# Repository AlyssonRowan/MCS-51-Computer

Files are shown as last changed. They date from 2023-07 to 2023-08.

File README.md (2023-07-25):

# MCS-51-Modular-Computer

MCS-51 based highly modular computer system
-------------------------------------------

This project aims to bring forward an MCS-51 based 
computer system centered around a series of relatively
simple modules sharing a modular bus backplane.

The overall design uses a number of boards designed within 
the limitations of low-cost PCB prototyping houses and free
PCB design software, i.e.
- Two signal planes (front and back)
- A maximum board size of 100mm x 100mm
  (yes, I know that some of them limit you to 100 x 80mm)
- A maximum of 300 connections per PCB
- A maximum of 2 signal (or groundplane) layers

Three card sizes have been defined and templates generated
based on the 1U Eurocard - 
- Full 1U Eurocard (100mm x 160mm)
- Half 1U Eurocard (100mm x 80mm)
- Short 1U Eurocard (100mm x 100mm)

These templates include placement masks for the bus connectors

NOTE:
----
Some of the simpler boards exist only as PCB files,
in these cases, component values are marked on-board
instead of component references.

The affected boards are:
- Modular Backplane (2 boards)
- 4-slot Production Backplane
- Integrated Backplane (MOBO and daughterboard)
- Bus Daisy-Chain board

Central Processor Board
-----------------------
- HMC-PR-1 AT89s51 Processor Board

The processor chosen for this project is the Atmel
AT89S51 and AT89S52 microcontroller. These have
4k and 8k of ISP Flash Memory respectively.

The processor board is set up without user SRAM and 
is ready to accept firmware as a basic development 
board. The serial lines are buffered and brought out 
to a header (TTL signals) for connection to a user 
console. RS232 is available via the Front Panel board.

Console (serial) signals are also carried on the bus
ready for embedded terminal hardware.

Main Memory Boards
------------------
- HMC-MMB-1   HY6264A (8k x 8bit SRAM) x 4
- HMC-MMB-2 - Configurable W24257AJ (32k x 8bit SRAM)

Two versions have so far been designed 
- one accepts a 32k x 8 fast SRAM chip, and is 
configurable in 8kB blocks.
- the second accepts up to 4 8k x 8 fast SRAM chips

Both versions may be located in upper OR lower memory space.
Up to two of these boards may be installed.

Program ROM Boards (Under development)
------------------
Ultimately, these boards will accept

- UV-EPROM
- EEPROM
- FLASH PROM

And will provide storage for compiled programs
(upper PStore) and System programs (lower PStore)

Modular Computer Bus
--------------------
The decision was made to use low-cost, highly available
standard 0.1" double row headers in order to reduce the 
board pin count while providing just a few spare lines 
above the bus minimum requirement. These are the same 
connectors formerly used for PC floppy and hard disk 
drives.

Although polarity is respected, just in case ribbon cable
is used, it is actually maintained by the polarisation 
forced by the dissimilar connectors on the backplane.

Modular Backplane
-----------------
- HMC-MB-1 (Slot A)
- HMC-MB-2 (Slot B)

The backplane comprises two boards, one carrying the 
40-way bus that includes the default signals from the 
MCS-51 MPU and the other, a 24-way bus with additional 
signals and 5V power. This second board also includes
decoupling capacitors per backplane slot.

The two boards are designed to sit side by side, and are
able to be stacked, extending the basic backplane from 
the basic five slots to (theoretically) any number of 
slots. It is not recommended that more than two modules
be daisy-chained without bus terminations.

A separate, hard wired 5.0V 2A (or more) power supply is
required to power the bus.

M2 mounting holes are provided for attachment of lateral 
support bars (Grounded, recommend: 6mm square Aluminium,
use M2 stainless washers to stand off from PCB) and cage 
sides (Isolated, recommend: 4mm acrylic). Half-holes are 
provided on the junction between the two boards in order
to facilitate a third point of attachment to the support 
bars.

Integrated Backplane
--------------------
- HMC-IB-1 (MOBO)
- HMC-IB-2 (Bus)

This is a pair of boards that are stacked using extended 
pin header sockets. 

The motherboard is a single 100mm square board which
includes basic front panel functionality and power feed
to the bus. A separate, hard wired power supply (5.0V 2A) 
is required.

The daughterboard provides a 4-slot bus powered via the 
motherboard.

It is recommended that this item not be daisy-chained
without very careful consideration. The board is fused
at 2A.

There is no RS232 console option on this PCB. This needs
to be provided separately if required. 

A low frequency clock "pulse" generator is provided for 
applications that require a low-frequency, semi-stable 
clock pulse for operation in the development stage.

The daughter board, built with standard sockets (i.e.
not wire-wrap form) may be used independent of the parent
board as a simple, no-frills 4-slot backplane. A mountable
version of this PCB is available.

With only a plug and a socket, the daughter board could 
also be used as a slot extender for service use.

4-Slot Production Backplane
---------------------------
- HMC-PB-1

This is functionally identical to the 4-slot daughterboard
for the integrated backplane kit, though with the addition
of mounting holes.

Daisy Chain Boards
------------------
- HMC-DCB-1 Short link for Modular Backplane use
- HMC-DCB-2 Long link for integrated backplane use

These board are supplied as two separate PCBs.

One narrow PCB for interlinking two Modular Backplane
segments while maintaining system board separation.
The wider is for linking an integrated backplane with 
a modular backplane segment.

Linking an integrated backplane with a modular backplane
is not recommended other than for development purposes.

Active Bus Terminator
---------------------
- HMC-ABT-1
While not strictly necessary, this short board is designed
to be inserted in the first and last physical slots on the 
bus, and should reduce signal reflections and timing issues
on the bus - especially when a longer bus is used.

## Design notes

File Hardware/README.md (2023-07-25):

HARDWARE
--------

Assemblies are divided into the following categories:

- (a) Templates
- (b) Core Components
- (c) Enhanced Options
- (d) Advanced Options
- (e) Fun and Aesthetic Options
- (f) Sensors and Ancillary Options
- (g) Support Hardware

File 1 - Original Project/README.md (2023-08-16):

# Original Project
**Elektor BASIC Computer**
*Elektor December 1987*

For a while, the MCS-51 range of microcontrollers 
was probably the most accessible on the market. 
The introduction of the 8052AH-BASIC gave a number
of hobbyists their first taste of microcontrollers, 
with the capacity to create a single-board computer
that was both a control system and a development 
system using a high-level language as opposed to
having to face the challenge of programming in 
assembler.

The project articles are included in their entirity.

Sadly the 8052AH-BASIC is no longer available.

I still use the board I built at that time even 
though it is now more than 30 years old.

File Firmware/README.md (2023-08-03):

# MCS-51 Modular Computer - Firmware

BASIC-52
--------

BASIC-52 was originally developed by Intel for their
8052AH-BASIC chip - an 8052 microcontroller with an 
on-board BASIC interpreter.

Please consider this to be a codebase from which to
develop your own MCS-51 support firmware.

V1.0 was the original release on these devices, but 
was rapidly supplanted by V1.1 which included a number 
of enhancements and bugfixes.

V1.1 continued to be supplied throughout the life of the
device, even though there were bugs in parts of the code.

V1.1++ was a patch for the V1.1 ROM image correcting the
most severe of these bugs.

V1.2 was independently developed to enable 8032 and 8052
devices to run using an off-chip ROM.

V1.3 is designed for devices to run code that allows for
the programming of FLASH PROMs

WARRANTY
--------

None of this software carries any warranty whatsoever and
MAY NOT be used for mission-critical applications including
but not limited to avionic systems, vehicle system control,
medical or safety systems.

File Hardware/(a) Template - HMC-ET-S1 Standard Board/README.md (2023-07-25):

HMC-ET-S1 Standard Board
------------------------

This schematic template may be used with any of the 
standard board PCB templates.

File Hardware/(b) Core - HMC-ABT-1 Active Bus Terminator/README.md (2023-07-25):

Active Bus Terminator
---------------------
- HMC-ABT-1

NOTE: 2 terminators are required if used.

While not strictly necessary, this short board is designed
to be inserted in the first and last physical slots on the 
bus, and should reduce signal reflections and timing issues
on the bus - especially when a longer bus is used.

It may be necessary to adjust the target voltage of one or
both terminator channels in order to reduce standing current 
on the bus.

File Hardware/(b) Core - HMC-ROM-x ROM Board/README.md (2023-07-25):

HMC-ROM-1 - 2764/27128 ROM Board v1.00
--------------------------------------

This is an interface designed to allow a pre-written EPROM
to be read by the processor. Both 2764 and 27127 EPROMs
may be used. The device only appears in the /PS address space

While the board may be configured by 8k blocks, while using
27128 EPROMs, the lower address should always be on a 16k 
boundary.

PROMs placed at the lower limit of the upper 32k of memory
(i.e. starting at 8000H) will allow the MCS-51 BASIC-52 
interpreter to access stored programs directly.

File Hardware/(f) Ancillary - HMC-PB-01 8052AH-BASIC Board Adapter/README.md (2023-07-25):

HMC-PB-01 8052AH-BASIC Board Adapter
------------------------------------

This PCB is designed to consolidate the signals on
the original Elektor 8052AH-BASIC Basic Computer
project board for compatibility with the MCS-51
Modular Computer.

Note that without modification, the console port
is NOT brought out to the bus and that a second
serial port output is available, exposed at the
port on this board.

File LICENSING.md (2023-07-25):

The content of this repository is released under the terms
of the GNU GENERAL PUBLIC LICENSE Version 3

Hardware
--------
While the ownership of the intellectual property of the
hardware is entirely in the hands of the owner of this 
repository, it carries some limitations from the software 
used to design it.

The version of DipTrace used is limited to non-commercial
applications only, so any derivative works would need to 
be re-developed using a less restrictive application.

The design paradigm, however, is based on the use of 100mm
wide PCBs and a shared bus design. You are asked to respect 
both of these factors in your own application in order to
maintain functional and physical compatibility.

Software & Firmware
-------------------
The firmware for this project is fixed firmly as a derivative 
work and will be subject to the copyrights of its various
owners. 

Attribution and Derivative Works
--------------------------------
You are asked to leave all copyright and attribution notices
in the source files of your derivative works.

EGO: You are asked to contact the owner of this repository 
should you find it useful.

Limitations and Liability
-------------------------
This hardware and software property is shared without cost. 
No representation as to merchantability or fitness for purpose
is made whatsoever. Liability for damage consequential to
using any part of this project lies entirely in the hands of 
the user.

Specific exclusions:
No part of this project is to be used for any medical, clinical,
avionic or other system where software or hardware failure could
lead to losses, injury or death. Those systems are designed by
specialist experts for a very good reason.

A.Rowan, 09 July 2023

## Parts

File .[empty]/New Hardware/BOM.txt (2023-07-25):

HMC-XXX-X BoardName

Line	Ref Des		        			Name			Value		QTY
---------------------------------------------------------------------------------------------------

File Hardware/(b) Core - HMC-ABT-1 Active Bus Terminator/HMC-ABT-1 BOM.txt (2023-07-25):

HMC-ABT-1  Active Bus Terminator v1.00

Line	Ref Des		        			Name			Value		QTY
---------------------------------------------------------------------------------------------------
1	C1, C2, C3					Capacitor Polarised	100uF 6.3V	3
2	C4, C5,						Capacitor Polarised	47uF 6.3V	2
3	C6, C7, C8, C9, C10, C11, C12, C13, C14		Capacitor		0.1uF		9
4	J1A						34-pin angle header, Male, 2.54mm	1
5	J1B						40-pin angle header, Male, 2.54mm	1
6	Q1, Q2						2N4923G					2
7	R3, R4,						Resistor		56R 1/4W	2
8	R5, R6, R7, R8, R9, R10, R11, R12, R13		SIP 9 Res (commoned)	1k0		9
9	TP1, TP2, TP3, TP4, TP5,			TESTPOINT				5
10	U1						LM358N					1
11	VR1, VR2					201XR103B		100k		2

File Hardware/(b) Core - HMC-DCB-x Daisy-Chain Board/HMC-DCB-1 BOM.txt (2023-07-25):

HMC-DCB-1  Daisy-Chain Board (short) v2.00

Line	Ref Des		        			Name			Value		QTY
---------------------------------------------------------------------------------------------------
1	J1A, J2A					40 pin straight header, FEMALE, 2.54mm	2
2	J1B, J2B					34 pin straight header, FEMALE, 2.54mm	2

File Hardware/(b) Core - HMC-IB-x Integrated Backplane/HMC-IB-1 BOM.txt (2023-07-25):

HMC-IB-1  Integrated Backplane MOBO v1.65

Line	Ref Des		        			Name			Value		QTY
---------------------------------------------------------------------------------------------------
1       C1, C2                                          Capacitor, polarised    250uF 6.3V      2
2       C3, C4, C5, C7, C10                             Capacitor, polarised    100uF 6.3V      5
3       C6                                              Capacitor               0.1uF           1
4       C9                                              Capacitor               10nF            1
5       D1                                              LED-5R_Red              5mm Round       1
6       D2, D3, D4, D5, D6, D7, D8, D9                  LED-3R_Red              3mm Round       8
7       J2, J3, J5, J7, J8, J11, J12, J13, J14          2 pin straight header, FEMALE, 2.54mm   9
8       J4, J6, J9, J10                                 6 pin straight header, FEMALE, 2.54mm   4
9       P1                                              14 pin straight header, MALE, 2.54mm    1
10      R1, R2, R4, R5, R6, R7, R8, R9                  RESISTOR                360R 0.125W     8
11      R3, R11                                         RESISTOR                3k9 0.125W      2
12      R10                                             Potentiometer, Preset   100k            1
13      S1, S2                                          7101SD9CQE              SPDT 5A 120V    2
14      S3                                              7201P3YCQE              DPDT 5A 120V    1
15      TP1, TP2, TP3                                   TESTPOINT                               3
16      U1                                              ULN2003BDR                              1
17      U2                                              NE555D                                  1

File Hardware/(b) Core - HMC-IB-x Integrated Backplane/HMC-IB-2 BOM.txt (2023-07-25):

HMC-IB-2  Integrated Backplane BUS daughterboard v1.10

Line	Ref Des		        			Name			Value		QTY
---------------------------------------------------------------------------------------------------
1	J1A						40-pin angle header, FEMALE		4
2	J1B						34-pin angle header, FEMALE, wire-wrap	4

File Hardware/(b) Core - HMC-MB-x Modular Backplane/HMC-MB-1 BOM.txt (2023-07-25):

HMC-MB-1  Modular Backplane A 

Line	Ref Des		        			Name			Value		QTY
---------------------------------------------------------------------------------------------------
5	J1A, J2A, J3A, J4A, J5A, J6A, J7A		40-pin straight header, FEMALE		7

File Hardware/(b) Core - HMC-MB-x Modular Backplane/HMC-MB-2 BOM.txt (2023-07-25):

HMC-MB-2  Modular Backplane A 

Line	Ref Des		        			Name			Value		QTY
---------------------------------------------------------------------------------------------------
1	J1B, J2B, J3B, J4B, J5B, J6B, J7B		34-pin straight header, FEMALE		7
2	C2, C3, C4, C5, C6				CAPACITOR, polarised	100uF 6.3V	5

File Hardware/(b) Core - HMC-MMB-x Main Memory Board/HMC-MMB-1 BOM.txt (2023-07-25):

HMC-MMB-1 - Main Memory Board (HY6264A x 4) v1.00 

Line	Ref Des		        			Name			Value		QTY
---------------------------------------------------------------------------------------------------
1	C1						Capacitor Polarised 	1000uF 16V	1
2 	C2, C3, C4, C5 					Capacitor		0.1uF		4
3 	D1 						1N5817G					1
4 	J1						40-pin angle header, Male, 2.54mm	1
5	J2						34-pin angle header, Male, 2.54mm	1
6	J3 						6-pin angle header, Male, 2.54mm	1
7 	JP1, JP2, JP3, JP4				Jumper Point 3-in-line, 2.54mm		4
8	U1, U2, U3, U4					HY6264A					4
9	U1, U2, U3, U4					Socket, 22pin 				4

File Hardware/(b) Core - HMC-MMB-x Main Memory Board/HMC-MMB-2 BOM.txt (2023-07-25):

HMC-

Line	Ref Des		        			Name			Value		QTY
---------------------------------------------------------------------------------------------------
1 	C1, C4 						Capacitor		0.1uF 		2
2 	C2 						Capacitor Polarised	1000uF 16V	1
3	D1						1N5817G 				1
4	J1						40-pin angle header, Male, 2.54mm	1
5	J2						34-pin angle header, Male, 2.54mm	1
6	J3 						6-pin angle header, Male, 2.54mm	1
7	JMP1						Jumper Point 3-in-line, 2.54mm		1
8 	JMP2, JMP3, JMP4, JMP5				Jumper Point 3-square, 2.54mm		4
10	U4						W24257AJ				1

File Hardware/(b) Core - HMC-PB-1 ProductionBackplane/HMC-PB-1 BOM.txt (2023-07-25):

HMC-PB-1  ProductionBackplane (4 slot bus) v1.00

Line	Ref Des		        			Name			Value		QTY
---------------------------------------------------------------------------------------------------
1	C1						Capacitor Polarised	100uF 6.3V	1
4	J1A, J2A, J3A, J4A				40-pin straight header, FEMALE		1
5	J1B, J2B, J3B, J4B				34-pin straight header, FEMALE		1

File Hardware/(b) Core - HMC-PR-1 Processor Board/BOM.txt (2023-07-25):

HMC-PR-1  Processor Board v1.20

Line	Ref Des		        			Name			Value		QTY
---------------------------------------------------------------------------------------------------
1 	C1, C3, C4, C8 					Capacitor		0.1uF		4
2	C2						Capacitor Polarised	1000uF 16V	1
3	C5						Capacitor Polarised 	10uF 16V	1
4 	C6, C7						Capacitor		30pF		2
5	D1 						1N5817G					1
6	J1						40-pin angled header, MALE, 2.54mm	1
7 	J2						34-pin angled header, MALE, 2.54mm	1
8	J3						10-pin angled header, MALE, 2.54mm	1
9 	J4						8-pin angled header, MALE, 2.54mm	1
10	J5						6-pin angled header, MALE, 2.54mm	1
11	J6						14-pin angled header, MALE, 2.54mm	1
12	JP1						Jumper Point 3-in-line, 2.54mm		1
13	R1						Resistor		8k2 0.25W	1
14	R2						Resistor		SIL 10k *8	1
15 	SW1						SP (ON)-OFF				1
16	U1						74HCT154N				1
17	U2						AT89S52-24PU				1
18	U3						74HC34N					1
19	U4						74HCT573N				1
20	Y1						ECS-20-20-1		12MHz		1
21	Misc Hardware					Sockets for above ICs

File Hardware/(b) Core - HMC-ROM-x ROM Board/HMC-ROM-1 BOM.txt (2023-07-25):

HMC-ROM-1 2764, 128 ROM Board v1.00 

Line	Ref Des		        			Name			Value		QTY
---------------------------------------------------------------------------------------------------
1	C1						Capacitor Polarised	1000uF 16V	1
2	C2, C3						Capacitor		0.1uF		2
3	D1						1N5817G					1
4	J1						40-pin angle header, Male, 2.54mm	1
5	J2						34-pin angle header, Male, 2.54mm	1
6	J3						6-pin angle header, Male, 2.54mm	1
7	JMP1						Jumper 3-in-line, 2.54mm		3
8	JMP2, JMP3, JMP4, JMP5, JMP6, JMP7, JMP8, JMP9	Jumper 3-square, 2.54mm			8
9	R1, R2						Resistor		4k7 0.25W	2
10	U1						SN74HC21N				1
11	U3						27128A-2				1

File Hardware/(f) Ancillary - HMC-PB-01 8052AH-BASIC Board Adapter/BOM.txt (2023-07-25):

HMC-PB-01 8052AH-BASIC Board Adaptor v1.00

Line	Ref Des		        			Name			Value		QTY
---------------------------------------------------------------------------------------------------
1	D1						1N5817G					1
2	J1, J3						40-pin angle header, Male		2
3	J2						34-pin angle header, Male		1
4	J4						20-pin angle header, Male		1
5	J5						8-pin angle header, Male		1

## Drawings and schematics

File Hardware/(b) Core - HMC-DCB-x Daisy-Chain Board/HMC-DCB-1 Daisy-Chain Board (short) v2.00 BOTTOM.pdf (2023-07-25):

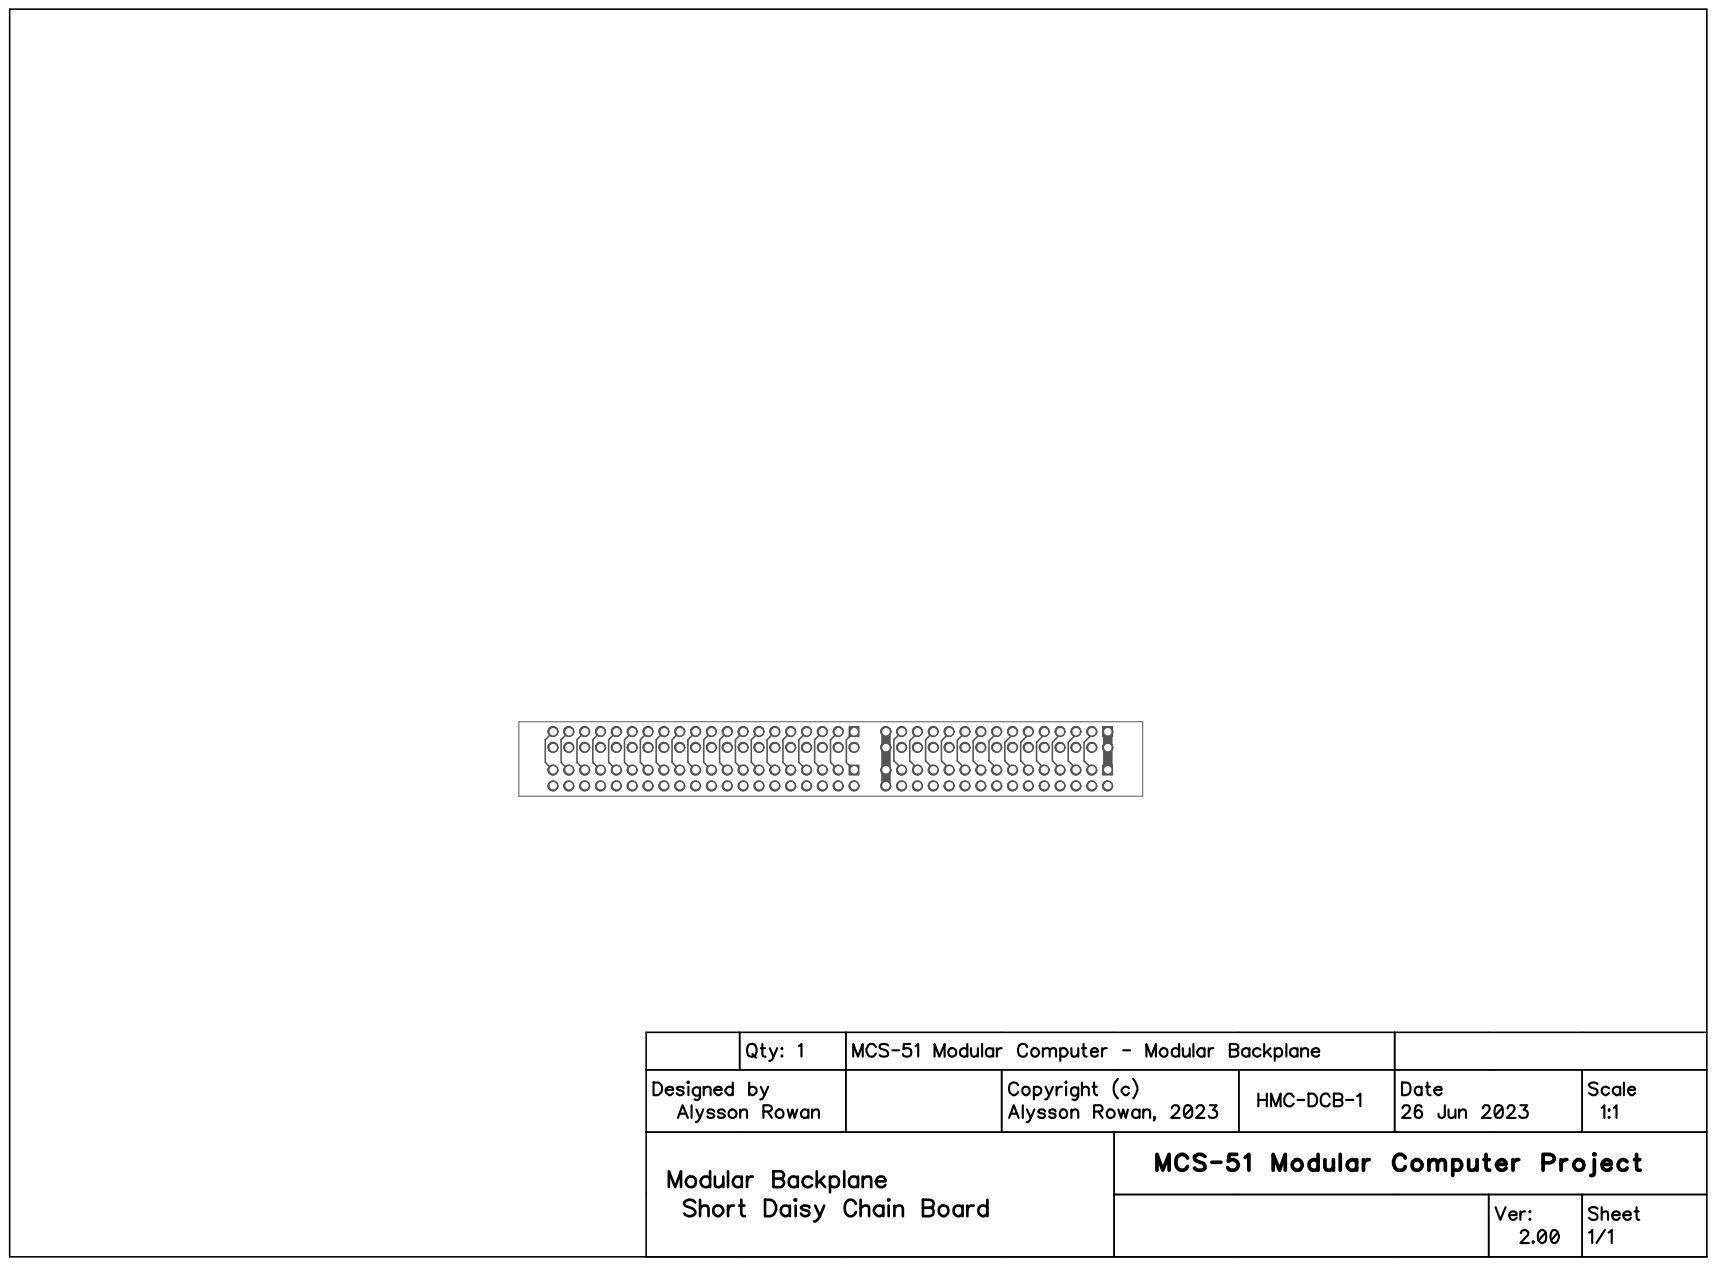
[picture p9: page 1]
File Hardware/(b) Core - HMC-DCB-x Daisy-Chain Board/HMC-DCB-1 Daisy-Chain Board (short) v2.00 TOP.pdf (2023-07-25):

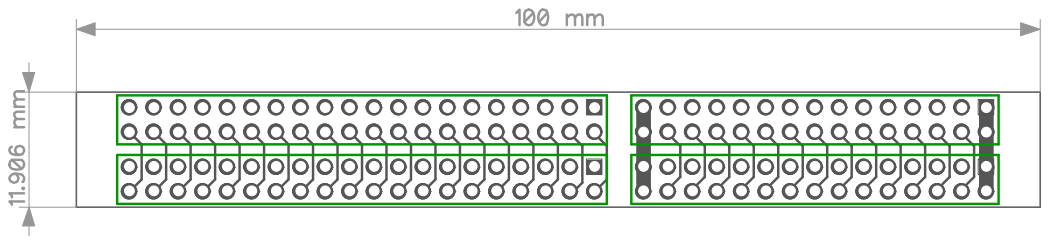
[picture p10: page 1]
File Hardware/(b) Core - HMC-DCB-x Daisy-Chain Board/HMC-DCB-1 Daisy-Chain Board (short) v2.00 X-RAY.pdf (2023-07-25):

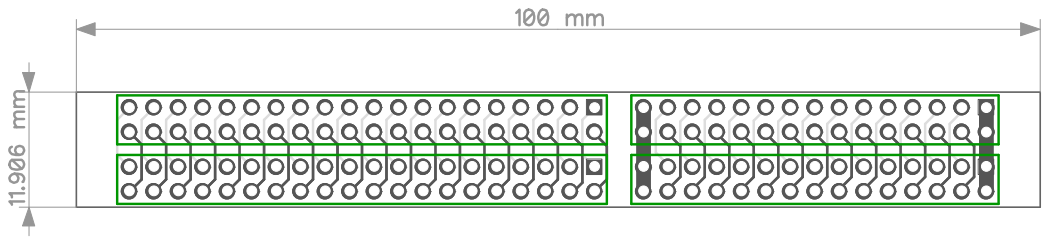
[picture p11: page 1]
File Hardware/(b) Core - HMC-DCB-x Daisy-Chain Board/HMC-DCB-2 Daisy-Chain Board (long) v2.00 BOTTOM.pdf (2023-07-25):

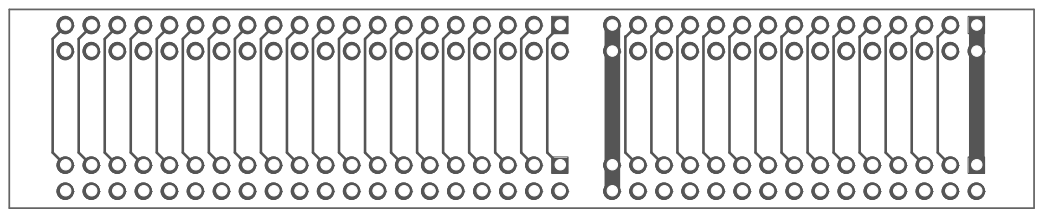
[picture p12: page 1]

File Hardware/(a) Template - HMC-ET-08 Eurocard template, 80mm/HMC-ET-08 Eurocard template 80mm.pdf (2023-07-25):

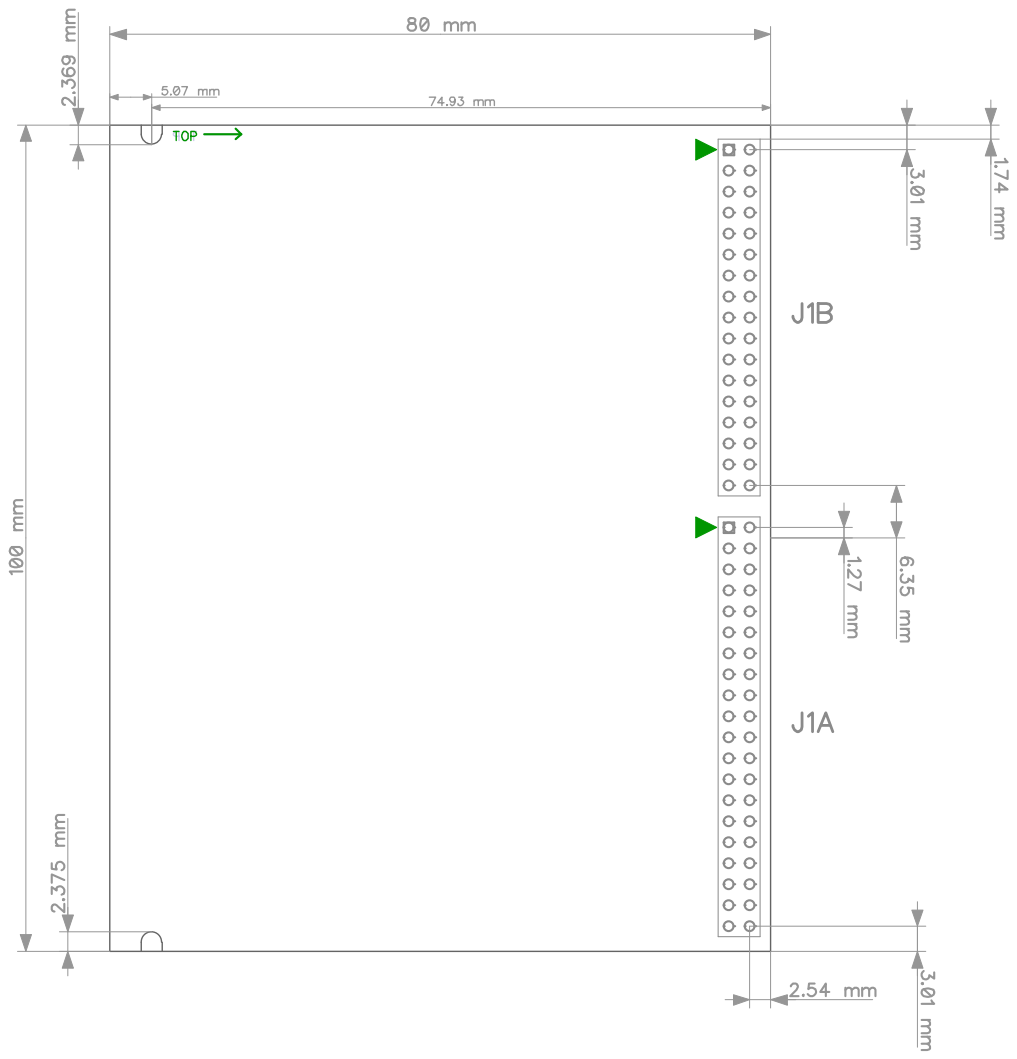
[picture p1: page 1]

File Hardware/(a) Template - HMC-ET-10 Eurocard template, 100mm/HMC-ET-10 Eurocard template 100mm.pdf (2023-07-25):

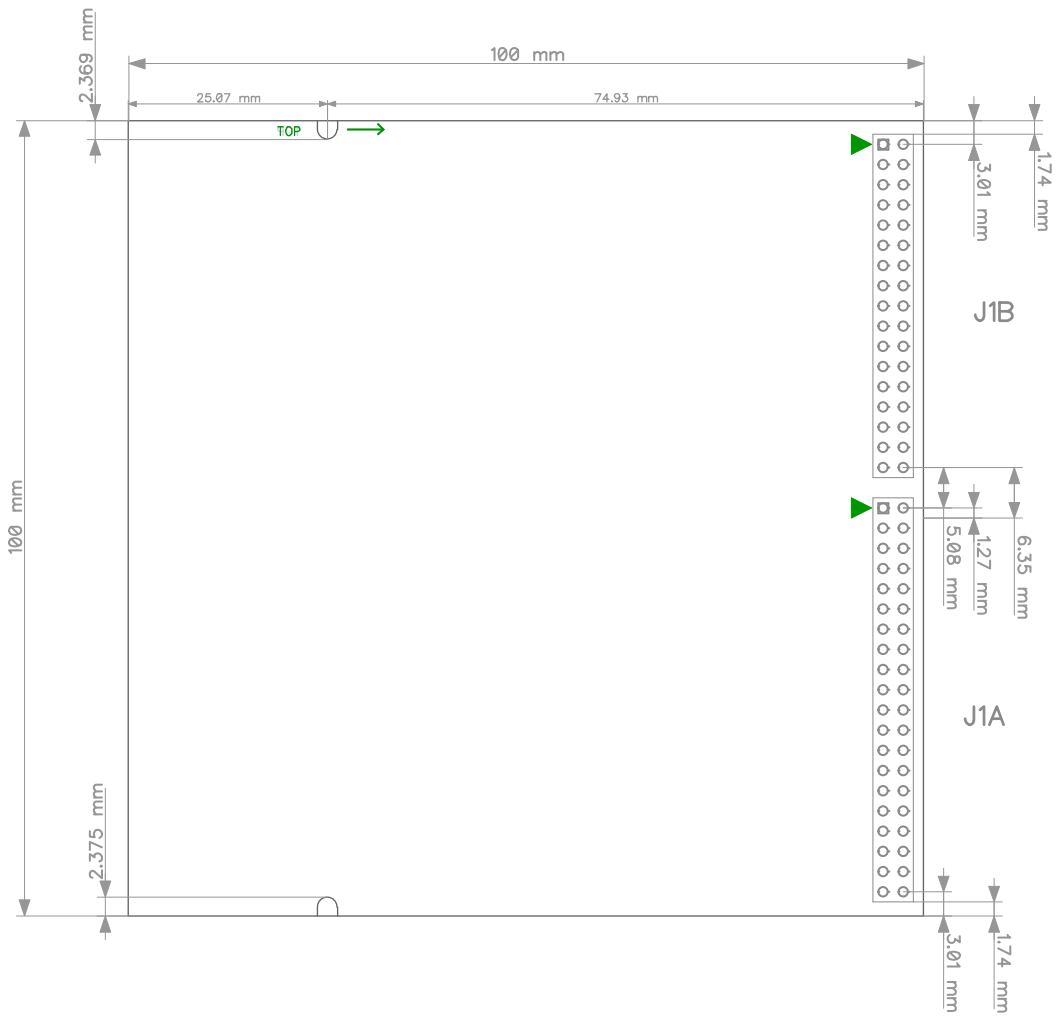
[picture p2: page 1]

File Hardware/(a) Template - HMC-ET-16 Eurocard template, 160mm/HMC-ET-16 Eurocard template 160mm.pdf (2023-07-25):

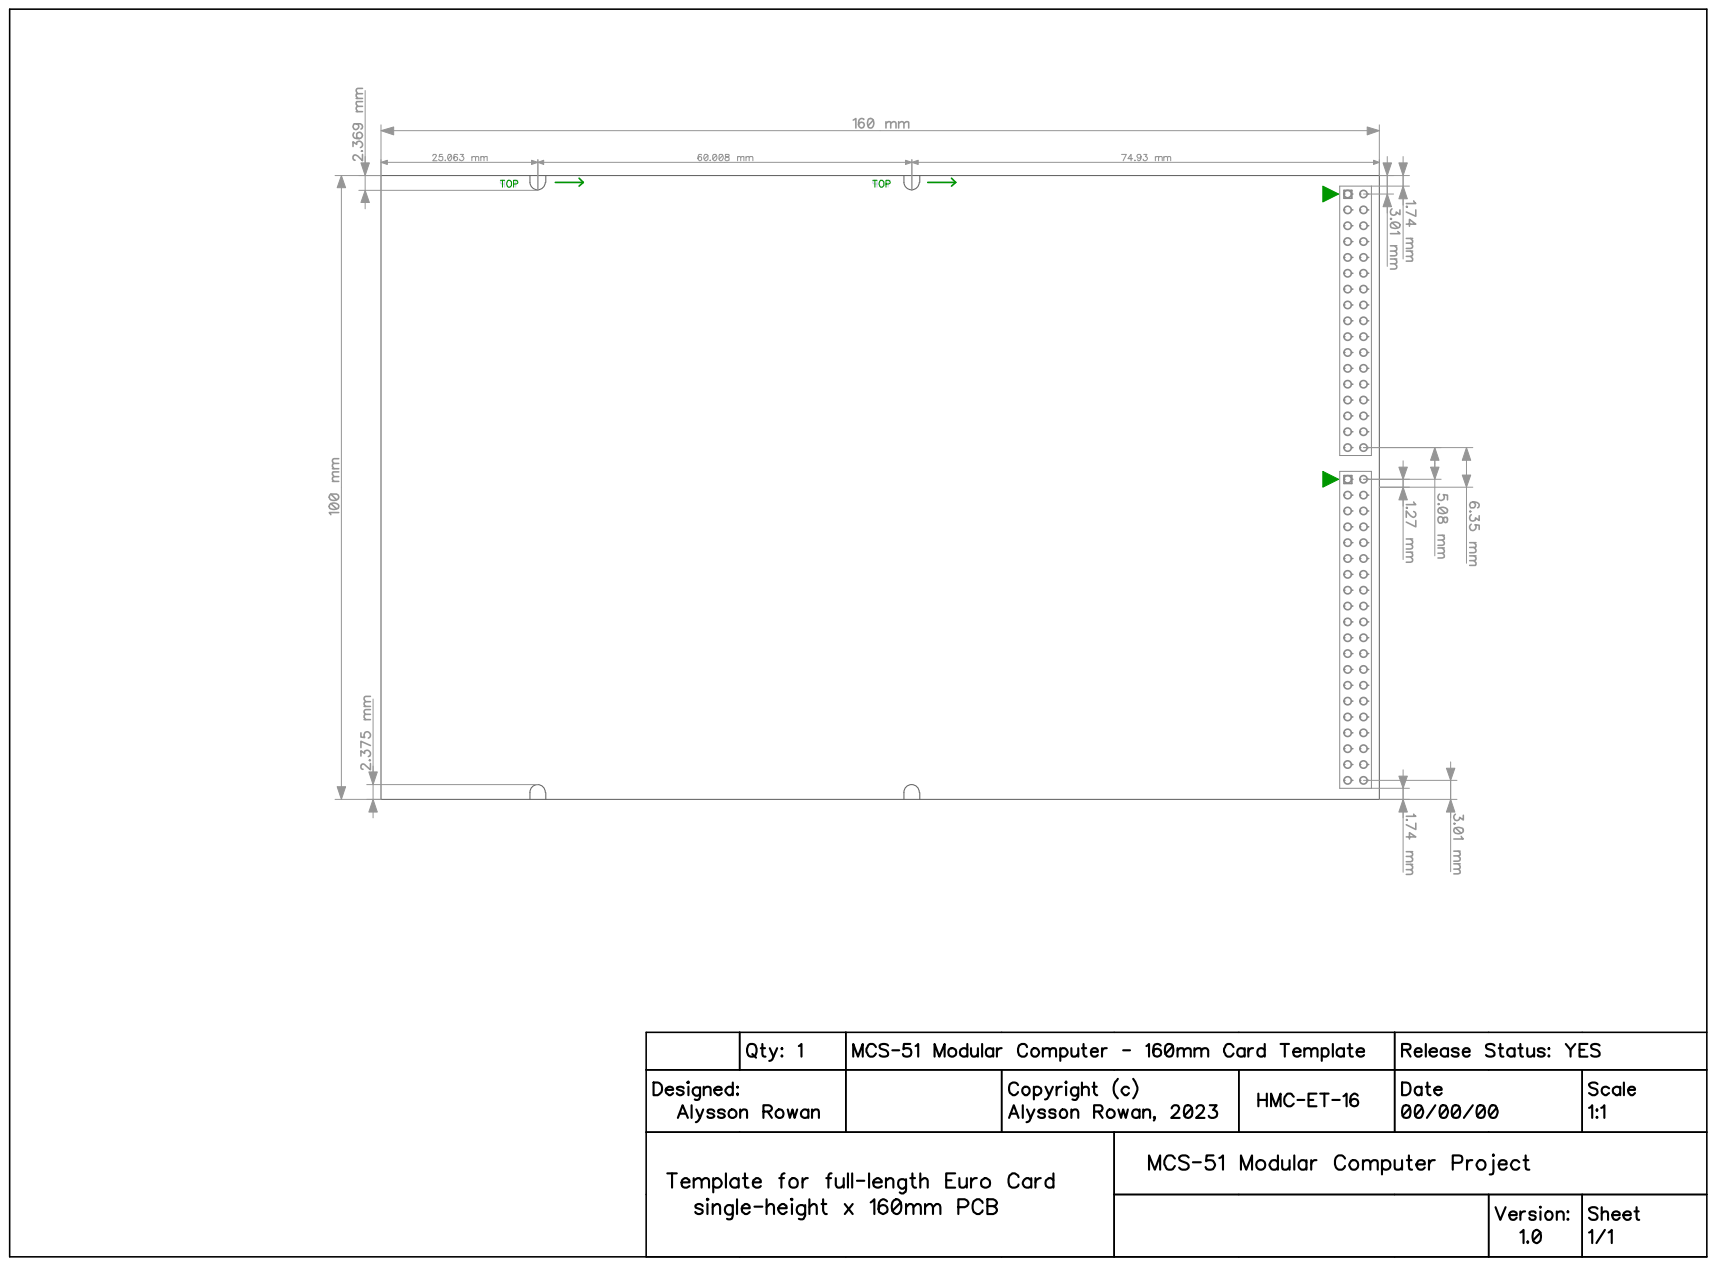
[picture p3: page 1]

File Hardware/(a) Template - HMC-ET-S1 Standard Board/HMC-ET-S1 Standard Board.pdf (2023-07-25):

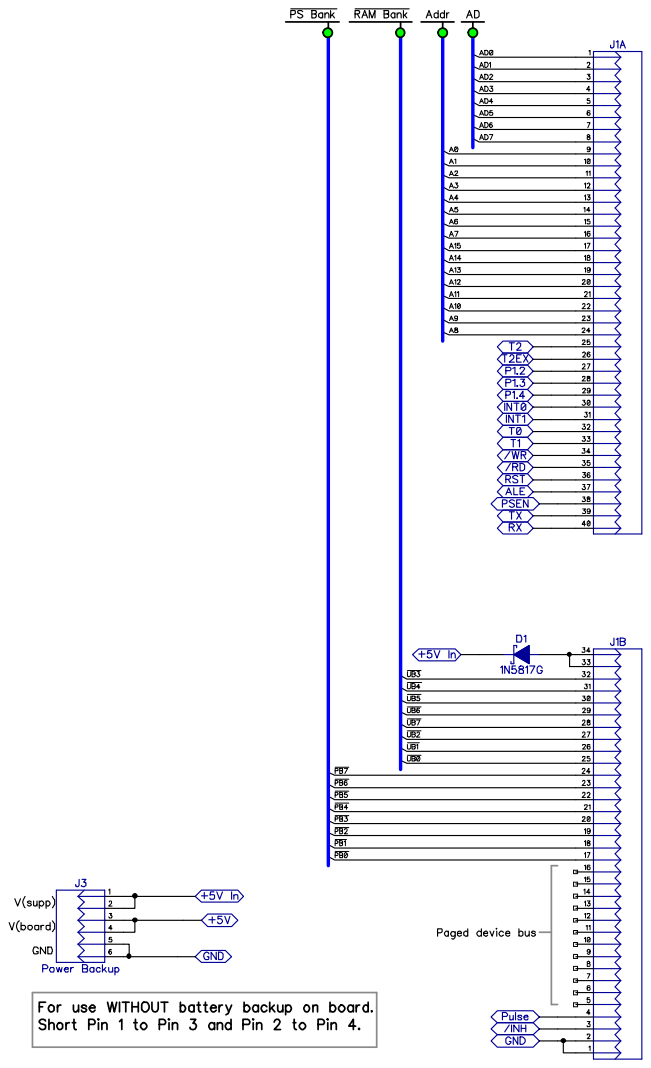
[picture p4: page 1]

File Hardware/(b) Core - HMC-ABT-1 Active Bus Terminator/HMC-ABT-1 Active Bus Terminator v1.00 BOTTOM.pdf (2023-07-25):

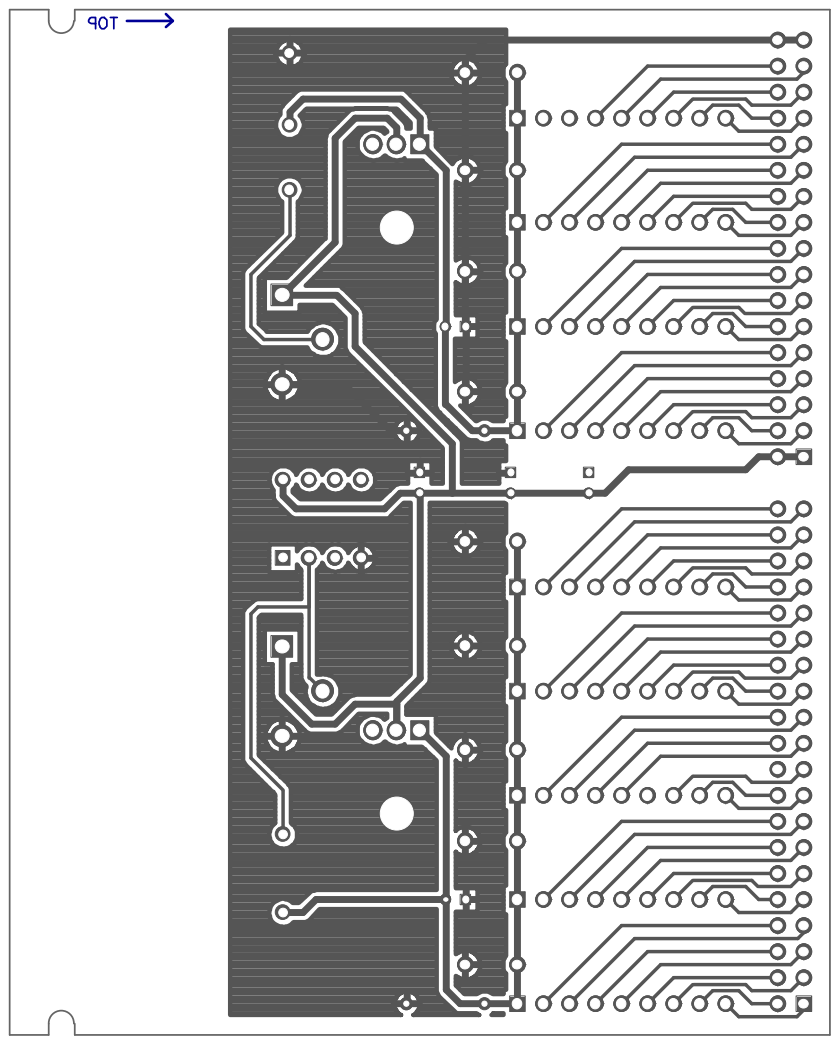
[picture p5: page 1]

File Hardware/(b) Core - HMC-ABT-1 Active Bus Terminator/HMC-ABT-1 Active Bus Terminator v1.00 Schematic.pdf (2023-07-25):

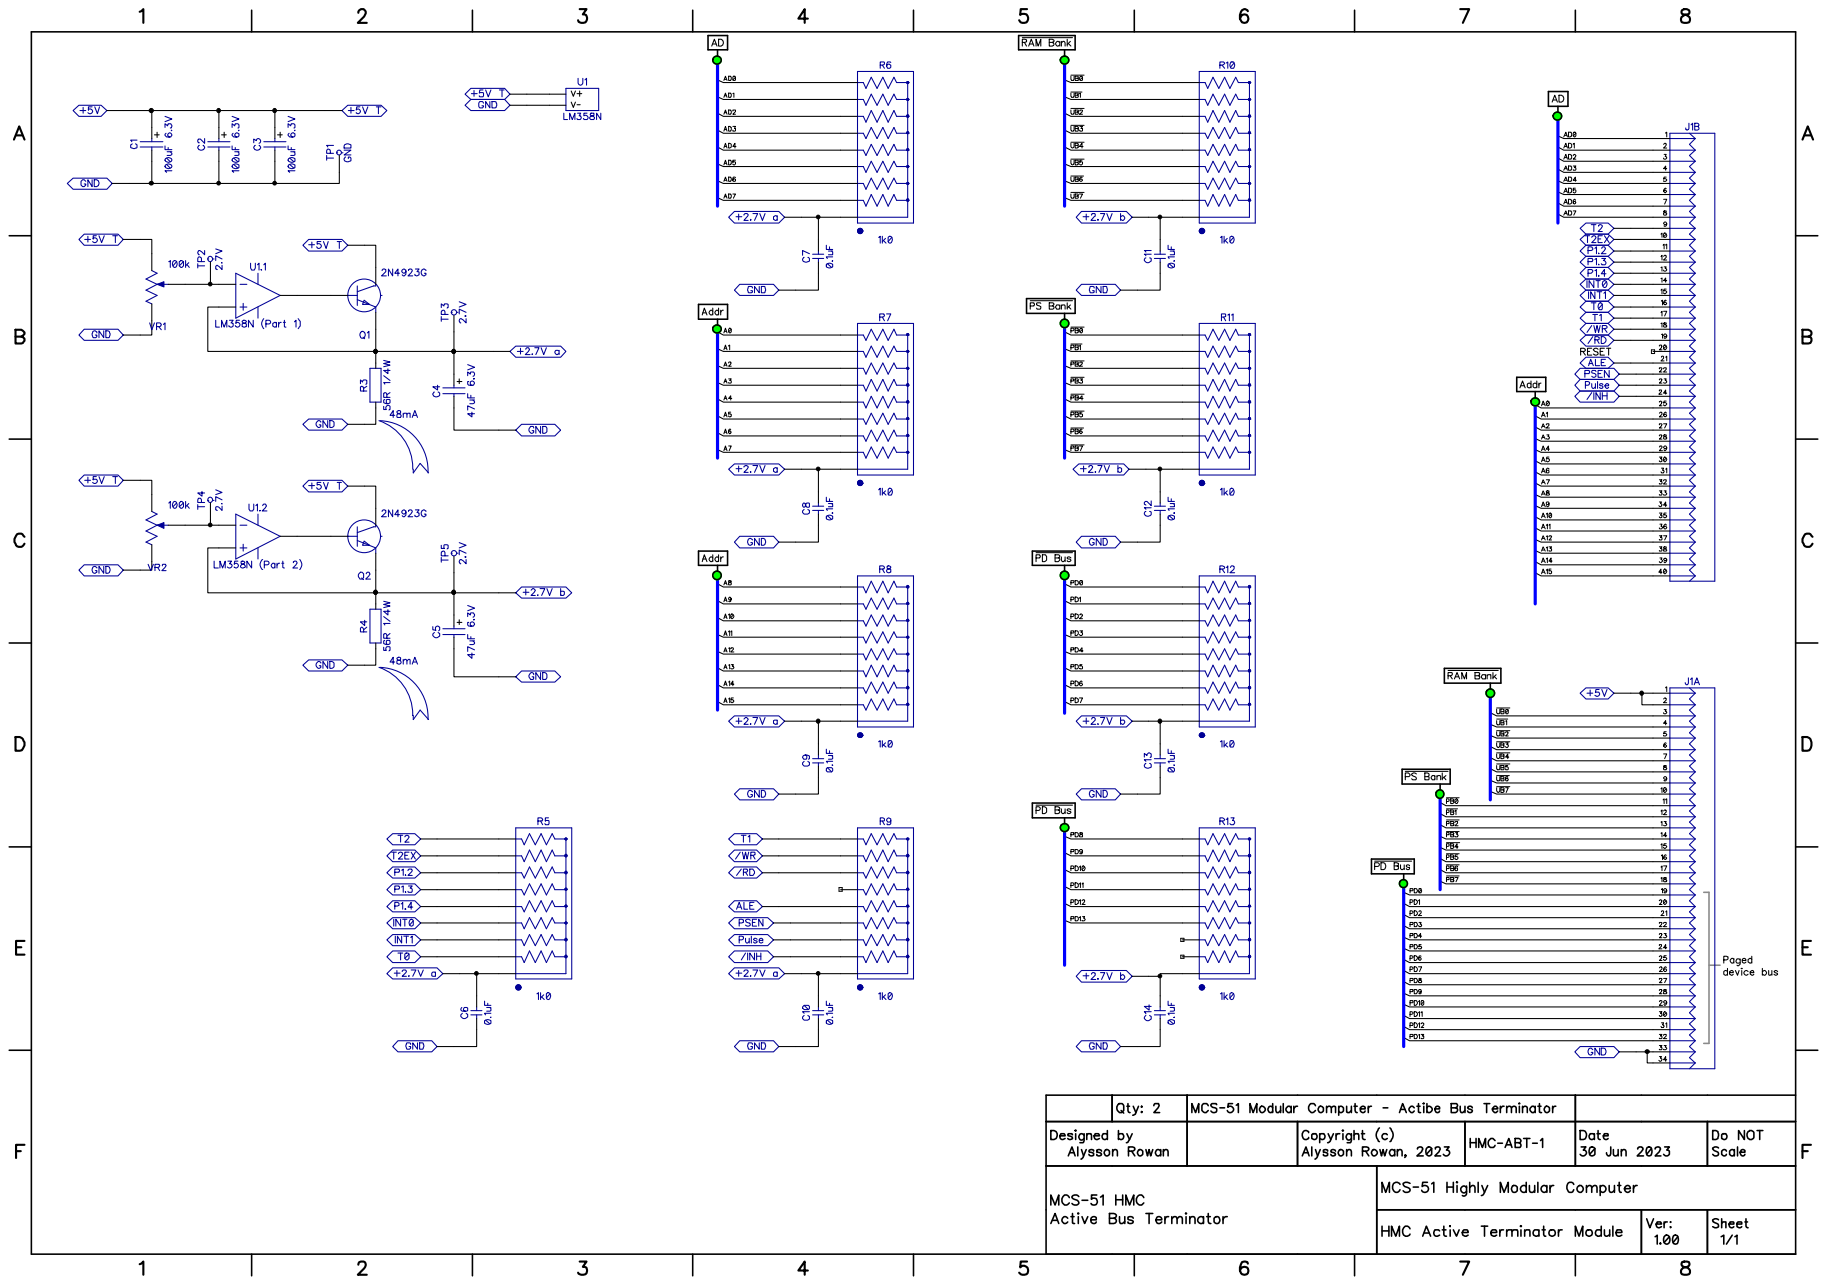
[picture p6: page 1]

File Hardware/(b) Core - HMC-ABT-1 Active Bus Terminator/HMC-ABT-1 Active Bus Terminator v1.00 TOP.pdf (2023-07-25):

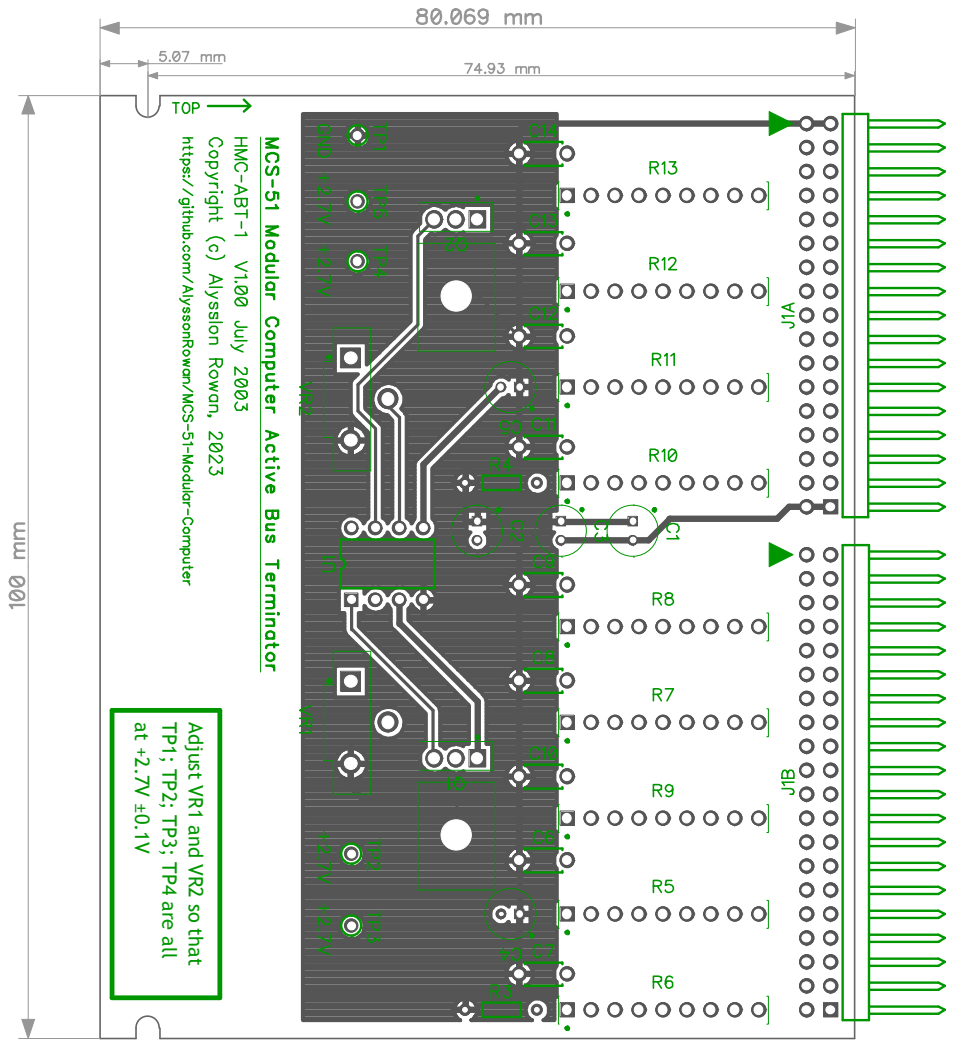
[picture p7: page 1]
TP1; TP2; TP3; TP4 are all

Adjust VR1 and VR2 so that

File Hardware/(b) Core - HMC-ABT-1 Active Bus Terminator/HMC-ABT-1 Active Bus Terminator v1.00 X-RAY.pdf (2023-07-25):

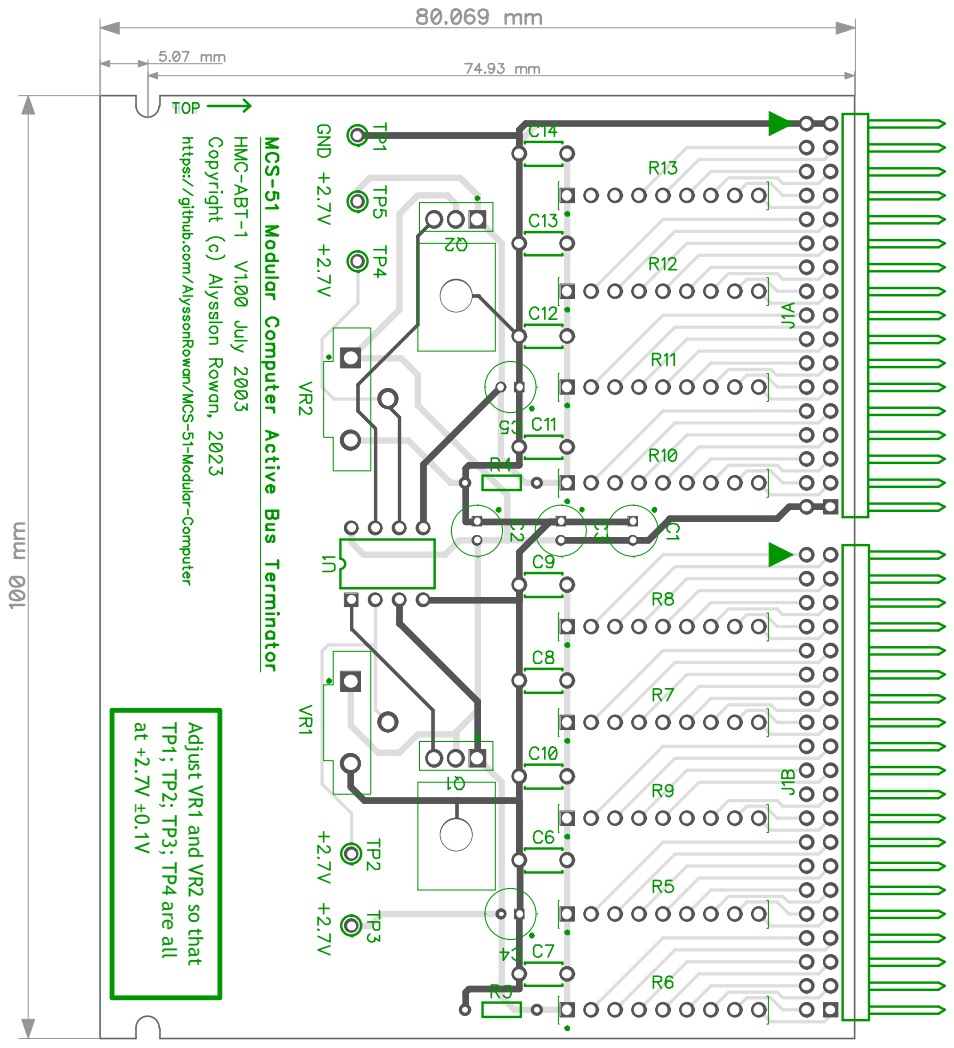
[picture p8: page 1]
TP1; TP2; TP3; TP4 are all

Adjust VR1 and VR2 so that
